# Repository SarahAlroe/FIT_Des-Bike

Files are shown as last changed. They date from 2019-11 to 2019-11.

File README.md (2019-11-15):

# FIT_Des-Bike

Et repo for Grundlæggende IT-produkt Design cykelprojektet.  
Formålet med projektet var at designe og installere et elektronisk system på en cykel.
Der blev i dette tilfælde valgt at bygge et indikator- og positionslys som kunne indikere sving og opbremsning.  
En demonstrationsvideo for projektet kan findes [her](https://youtu.be/tOHQS_oNwDI).

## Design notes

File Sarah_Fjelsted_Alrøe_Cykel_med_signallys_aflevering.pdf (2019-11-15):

Sarah Fjelsted Alrøe | Grundlæggende IT-Produktdesign | 2019-10-04
201905161 | | Dokumentation af cykel

# Cykel med signallys

Videodemonstration af cyklen er vedhæftet, og ellers tilgængelig ved: https://youtu.be/tOHQS_oNwDI

I denne aflevering dokumenteres arbejdet med cykelprojektet, der resulterede i en Arduino-baseret installation, som tilføjer positions-og indikatorlys der kan signallere sving og opbremsninger gennem henholdsvist knapper og et accelerometer. Først beskrives ideen til cyklen, herefter den tekniske udførsel af ideen, og endeligt resultatet, med overvejelser på begrænsninger og besværligheder.

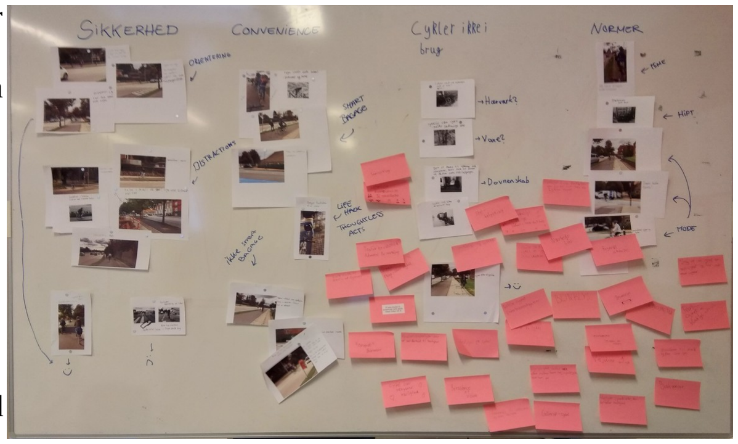
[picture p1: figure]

Der blev taget billeder af cykler og cyklister
i hverdagen. Disse blev grupperet for at
finde tendenser der kunne behandles. Ud fra
disse tendenser blev en række spørgsmål stillet, hvorpå en brainstorm blev udført. Begge ses på figur 1. Dette resulterede i en række ideer, hvorfra en blev udvalgt.

En af de tendenser som blev fundet var cyklisters manglende evne til at kommunikere deres intentioner med cyklen. Traditionelt rækker cylister deres hænder ud for at signallere drej eller stop. Ikke alle cyklister gør dette, og det kan være farligt at signallere hele vejen gennem
handlingen. Ideen til cyklen
er altså gøre signallering
lettere gennem et signal-

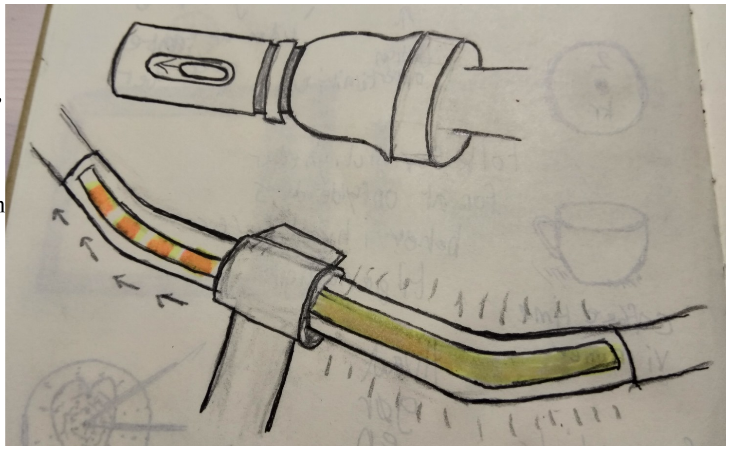
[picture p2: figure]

system i stil med det på biler, som kan indikere sving til højre/venstre, fremad kørsel, samt opbremsning. I styret indlejres slide-kontakter, som skubbes for at starte
indikation af et sving. På baggagebæret og styret
monteres lys som animerer
for at vise cyklistens
intentioner og gøren.
Kontakterne på styret samt lyset er illustreret på figur 2. Figur 2: Skitse af slide-kontakter og lys på styr

Figur 1: Gruppering af observationer og brainstorm

201905161 | Dokumentation af cykel

Der blev skitseret en indpakning til elektronikken som kunne monteres mellem bagagebæret og sædet (Figur 4). Ud fra skitsen blev en 1:1 skummodel konstrueret (Figur 3).

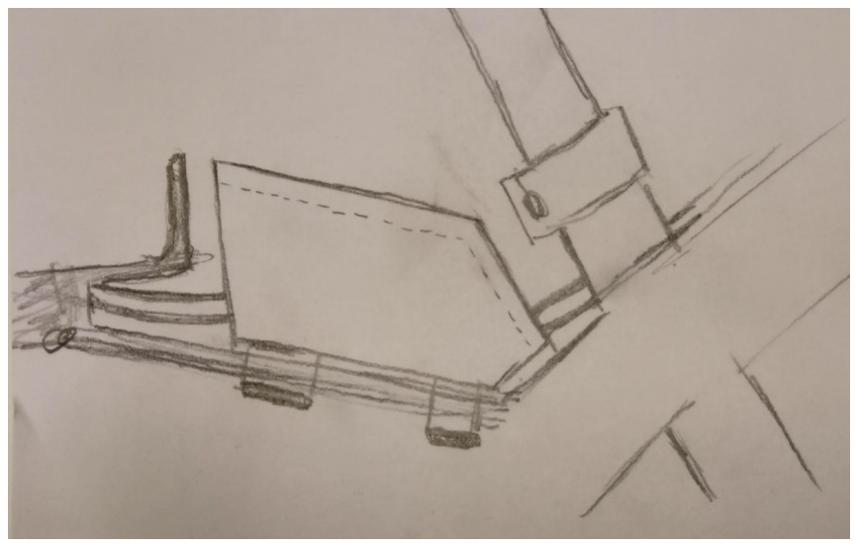
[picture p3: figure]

## Udførsel

Opsætningen består af en Arduino Nano forbundet til en usb power bank. Til Arduinoen er sluttet to
SK6812RGBW strips der sidder foran på cyklen, to

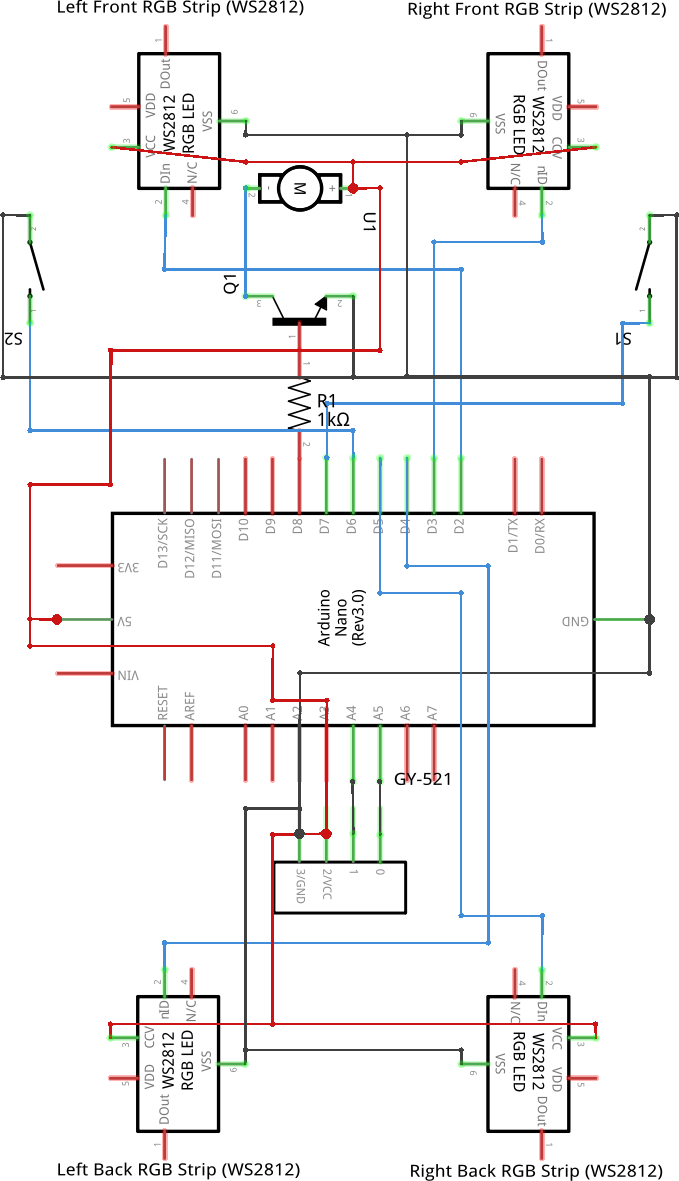
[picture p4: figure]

SK6812RGB strips der sidder bagpå, to pushbuttons som sidder på enden af styrets håndtag, en vibrations-motor på midten af styret drevet med en NPN transistor, samt et GY-521 accelerometer/gyroskop modul. Det fulde kredsløb er optegnet i figur 5.

## Blink

Der kan ved blink indikeres intentioner om at dreje til højre, venstre, eller at køre lige ud. Dette styres med de to knapper på styrets håndtag. For at indikere et drej skubber man sin hånd mod den knap, i hvis retning man ønsker at dreje. Dette fungerer analogt til hvordan man almindeligvis rækker ud for at indikere drej, og forhindrer på samme tid ikke cyklisten i stadig at gøre dette.
I software holdes to tilstande i form af boolean feltvariabler for om der drejes til højre eller venstre. Ved klik på knapperne skiftes disse variabler til deres modsatte værdi. Ud fra disse tilstande vælges mellem fire animationer: Almindeligt kørelys, højresving, venstresving og fremadkørsel som aktiveres ved at klikke i begge retninger. Blink-animationerne fungerer ved at blanke den givne side af LED’erne, og trække et

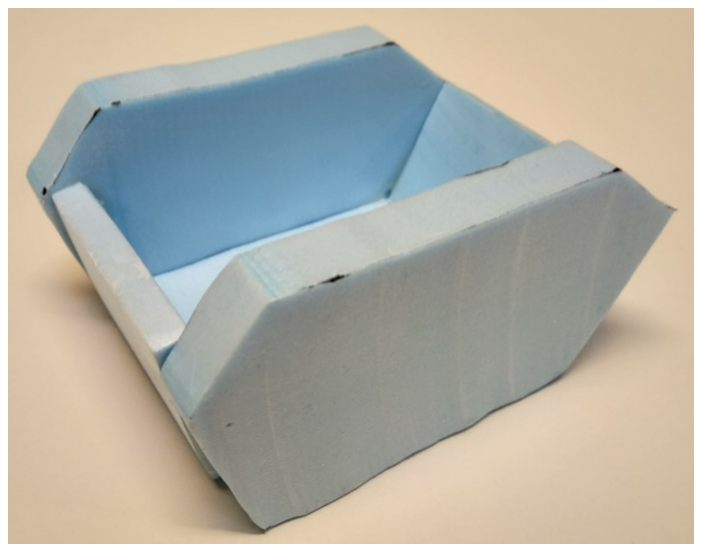
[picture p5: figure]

Figur 5: Kredsløbsdiagram over installationen på cyklen

Figur 4: Skitse af indpakning til elektronik

Figur 3: Skummodel af
indpakning til elektronik

201905161 | Dokumentation af cykel

orange lys i retnignen man drejer. Ved fremad-animationen blinkes begge sider, men lyset bevæger sig indad mod cyklen. Under blink drives foruden en vibrationsmotor for at indikere til cyklisten at de stadig blinker.

## Opbremsning

Opbremsning registreres ved brug af GY-521’ens accelerometer. Omtrendt hver 100ms måles accelerationen i bagudgående retning, og der holdes et løbende gennemsnit på denne værdi. Når den udjævnede værdi krydser over et eksperimentelt bestemt threshold niveau sættes en field variabel, som i animationerne får det røde baglys til at lyse stærkere, eller skifter fra sort til svag rød som baggrund hvis der blinkes.

## Resultat

I demo-videoen kan den endelige opsætning af lys mv. Ses. Mens det var tænkt at montere forlyset på styret, viste dette sig ikke praktisk, så det blev placeret under. Både for-og baglys blev monteret på krydsfinerplader, som blev stripset fast på cyklen. Ligeledes blev der i stedet for slide-knapper brugt simple microswitches på enden af håndtagene man bumper hånden imod.
Opsætningen har været monteret og taget i daglig brug over nogle dage, og nogle besværlighheder har her vist sig. Intet af den brugte elektronik er vandtæt, hvilket var et problem på regnvejrsdage. Elektronikken blev indpakket så godt som muligt i plastikposer vist på figur 6, og der blev taget specielle forhold for at holde cyklen tør. På grund af denne øgede påpasselighed er cyklen langt mere end normalt blevet taget med indendøre. Fordi lysene stikker ud fra cyklen har disse en tendens til at ramme ind i vægge, døre og borde, hvilket flere gange har ledt til at krydsfinerpladerne er knækket. Et tilfælde af dette ses på figur 7.

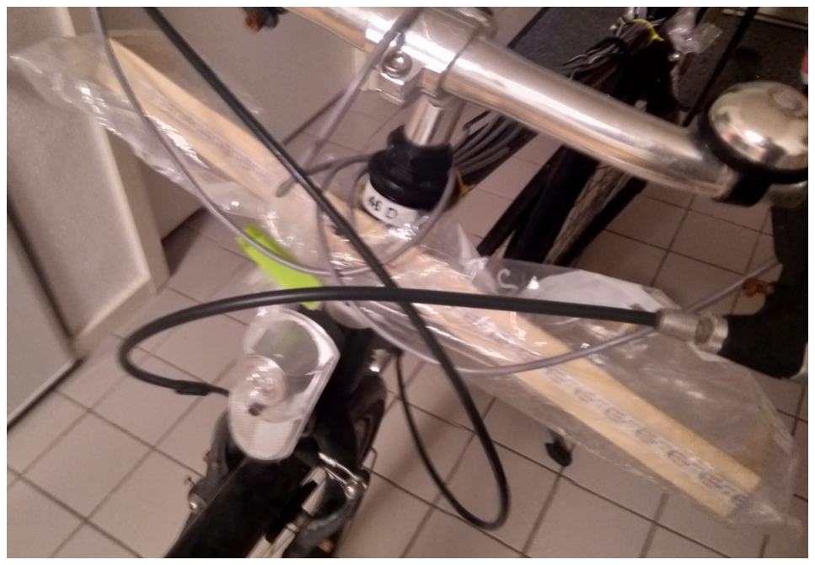
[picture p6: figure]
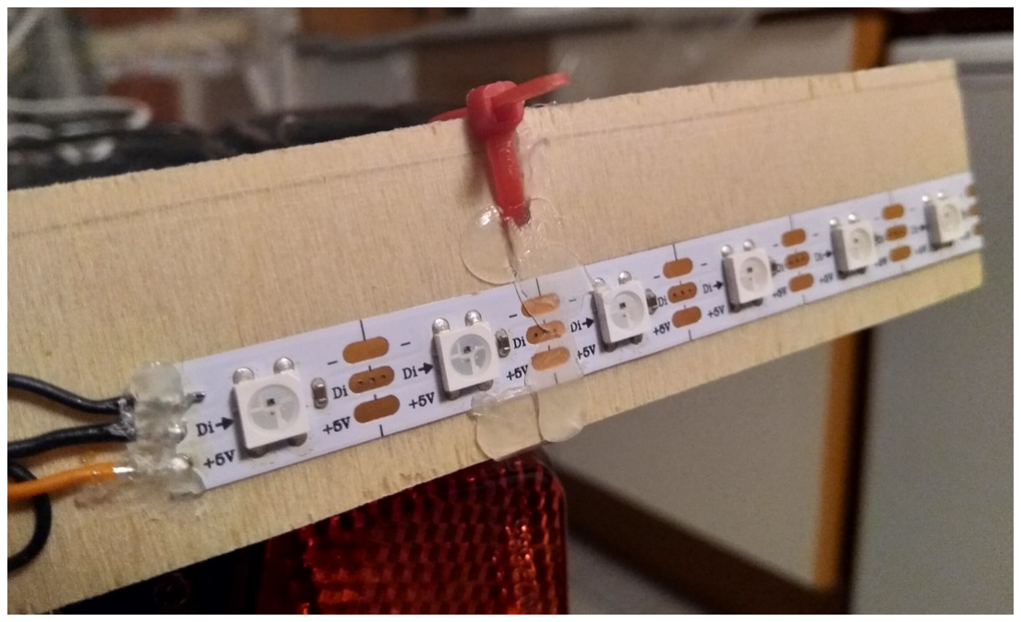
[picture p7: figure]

Figur 6: Lys pakket i plastic poser | Figur 7: Knækket baglys repareret med varmlim

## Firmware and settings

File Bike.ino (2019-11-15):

#include <movingAvg.h>
#include <NeoPixelBus.h>
#include <NeoPixelAnimator.h>
#include <EasyButton.h>
#include<Wire.h>

const int MPU = 0x68;

const int lfPin = 2;
const int rfPin = 3;
const int lbPin = 4;
const int rbPin = 5;

const int lButtonPin = 6;
const int rButtonPin = 7;
const int vibPin = 8;

const int frontNumPixels = 16;
const int backNumPixels = 12;
const uint16_t AnimCount = 1;

const RgbwColor frontIdleColor = RgbwColor(0, 0, 0, 50);
const RgbColor backIdleColor = RgbColor(50, 0, 0);
const RgbColor backIdleColorBreaking = RgbColor(255, 0, 0);
const RgbColor turnColor = RgbColor(255, 50, 0);
const RgbColor invTurnColor = RgbColor(0);
const int turnDarkenAmount = 1;
const int animationSpeed = 600;

const float vibPart = 0.25;

bool breaking = false;
bool turningLeft = false;
bool turningRight = false;

NeoGamma<NeoGammaTableMethod> colorGamma;
NeoPixelBus<NeoGrbwFeature, Neo800KbpsMethod> lfstrip(frontNumPixels, lfPin);
NeoPixelBus<NeoGrbwFeature, Neo800KbpsMethod> rfstrip(frontNumPixels, rfPin);
NeoPixelBus<NeoGrbFeature, Neo800KbpsMethod> lbstrip(backNumPixels, lbPin);
NeoPixelBus<NeoGrbFeature, Neo800KbpsMethod> rbstrip(backNumPixels, rbPin);
NeoPixelAnimator animations(AnimCount);

EasyButton lButton(lButtonPin);
EasyButton rButton(rButtonPin);

const int accFwOff = -874; //Experimentally reached value (Note: very device orientationd dependent)
const int breakingThreshold = 900; //Same
const int accMovingAvgCount = 10;
const int accReadDelay = 100;
unsigned long accLastRead = 0;
movingAvg avgAccFw(accMovingAvgCount);

void lButtonPressedCallBack() {
  if (turningLeft && turningRight) {
    turningLeft = false;
    turningRight = false;
  } else {
    turningLeft = ! turningLeft;
  }
}

void rButtonPressedCallBack() {
  if (turningLeft && turningRight) {
    turningLeft = false;
    turningRight = false;
  } else {
    turningRight = ! turningRight;
  }
}

void handleAnimState() {
  if (turningLeft && turningRight) {
    animations.StartAnimation(0, animationSpeed, ForwardAnimUpdate);
    return;
  }
  if (turningLeft) {
    animations.StartAnimation(0, animationSpeed, LeftAnimUpdate);
    return;
  }
  if (turningRight) {
    animations.StartAnimation(0, animationSpeed, RightAnimUpdate);
    return;
  }
  animations.StartAnimation(0, animationSpeed, IdleAnimUpdate);
}

int towardsClamped(int start, int target, int steps) {
  if (start == target) {
    return start;
  }
  int diff = target - start;
  int sign = (diff > 0) - (diff < 0);
  int dist = sign * steps;
  if (abs(dist) > abs(diff)) {
    dist = diff;
  }
  return start + dist;
}

RgbColor colorTowards(RgbColor start, RgbColor target, int maxAmount) {
  if (start.R == target.R && start.G == target.G && start.B == target.B) {
    return start;
  }

  int r = towardsClamped(start.R, target.R, maxAmount);
  int g = towardsClamped(start.G, target.G, maxAmount);
  int b = towardsClamped(start.B, target.B, maxAmount);

  return RgbColor(r, g, b);
}
RgbwColor colorTowards(RgbwColor start, RgbwColor target, int maxAmount) {
  if (start.R == target.R && start.G == target.G && start.B == target.B && start.W == target.W) {
    return start;
  }

  int r = towardsClamped(start.R, target.R, maxAmount);
  int g = towardsClamped(start.G, target.G, maxAmount);
  int b = towardsClamped(start.B, target.B, maxAmount);
  int w = towardsClamped(start.W, target.W, maxAmount);

  return RgbwColor(r, g, b, w);
}

void fadeStripTowards(NeoPixelBus<NeoGrbFeature, Neo800KbpsMethod> &strip, RgbColor color, int amount) {
  for (uint16_t indexPixel = 0; indexPixel < strip.PixelCount(); indexPixel++)
  {
    strip.SetPixelColor(indexPixel,
                        colorTowards(strip.GetPixelColor(indexPixel), color, amount));
  }
}
void fadeStripTowards(NeoPixelBus<NeoGrbwFeature, Neo800KbpsMethod> &strip, RgbwColor color, int amount) {
  for (uint16_t indexPixel = 0; indexPixel < strip.PixelCount(); indexPixel++)
  {
    strip.SetPixelColor(indexPixel,
                        colorTowards(strip.GetPixelColor(indexPixel), color, amount));
  }
}
void fadeIntervalTowards(NeoPixelBus<NeoGrbFeature, Neo800KbpsMethod> &strip, int i0, int i1, RgbColor color, int amount) {
  for (int i = i0; i <= i1; i++) {
    strip.SetPixelColor(i, colorTowards(strip.GetPixelColor(i), color, amount));
  }
}
void fadeIntervalTowards(NeoPixelBus<NeoGrbwFeature, Neo800KbpsMethod> &strip, int i0, int i1, RgbwColor color, int amount) {
  for (int i = i0; i <= i1; i++) {
    strip.SetPixelColor(i, colorTowards(strip.GetPixelColor(i), color, amount));
  }
}

void handleVib(float progress){
  if (progress<vibPart){
    digitalWrite(vibPin, HIGH);
  }else{
    digitalWrite(vibPin, LOW);
  }
}

void IdleAnimUpdate(const AnimationParam& param) {
  fadeStripTowards(lfstrip, frontIdleColor, turnDarkenAmount);
  fadeStripTowards(rfstrip, frontIdleColor, turnDarkenAmount);
  RgbColor backColor = breaking ? backIdleColorBreaking : backIdleColor;
  fadeStripTowards(lbstrip, backColor, turnDarkenAmount);
  fadeStripTowards(rbstrip, backColor, turnDarkenAmount);

  if (param.state == AnimationState_Completed)
  {
    handleAnimState();
  }
}

void ForwardAnimUpdate(const AnimationParam& param) {
  RgbColor backTurnColor = breaking ? backIdleColor : invTurnColor;
  float progress = param.progress;
  int index;

  handleVib(progress);

  fadeStripTowards(lfstrip, invTurnColor, turnDarkenAmount);
  index = (1.0f - progress) * lfstrip.PixelCount();
  fadeIntervalTowards(lfstrip, index - 1, index + 1, turnColor, turnDarkenAmount * 2);

  fadeStripTowards(lbstrip, backTurnColor, turnDarkenAmount);
  index = (1.0f - progress) * lbstrip.PixelCount();
  fadeIntervalTowards(lbstrip, index - 1, index + 1, turnColor, turnDarkenAmount * 2);

  fadeStripTowards(rfstrip, invTurnColor, turnDarkenAmount);
  index = (1.0f - progress) * rfstrip.PixelCount();
  fadeIntervalTowards(rfstrip, index - 1, index + 1, turnColor, turnDarkenAmount * 2);

  fadeStripTowards(rbstrip, backTurnColor, turnDarkenAmount);
  index = (1.0f - progress) * rbstrip.PixelCount();
  fadeIntervalTowards(rbstrip, index - 1, index + 1, turnColor, turnDarkenAmount * 2);


  if (param.state == AnimationState_Completed)
  {
    handleAnimState();
  }
}

void LeftAnimUpdate(const AnimationParam& param) {
  RgbColor backColor = breaking ? backIdleColorBreaking : backIdleColor;
  RgbColor backTurnColor = breaking ? backIdleColor : invTurnColor;

  float progress = param.progress;
  int index;

  handleVib(progress);

  fadeStripTowards(lfstrip, invTurnColor, turnDarkenAmount);
  index = progress * lfstrip.PixelCount();
  fadeIntervalTowards(lfstrip, index - 1, index + 1, turnColor, turnDarkenAmount * 2);

  fadeStripTowards(lbstrip, backTurnColor, turnDarkenAmount);
  index = progress * lbstrip.PixelCount();
  fadeIntervalTowards(lbstrip, index - 1, index + 1, turnColor, turnDarkenAmount * 2);

  fadeStripTowards(rfstrip, frontIdleColor, turnDarkenAmount);
  fadeStripTowards(rbstrip, backColor, turnDarkenAmount);

  if (param.state == AnimationState_Completed)
  {
    handleAnimState();
  }
}

void RightAnimUpdate(const AnimationParam& param) {
  RgbColor backColor = breaking ? backIdleColorBreaking : backIdleColor;
  RgbColor backTurnColor = breaking ? backIdleColor : invTurnColor;

  float progress = param.progress;
  int index;

  handleVib(progress);

  fadeStripTowards(rfstrip, invTurnColor, turnDarkenAmount);
  index = progress * rfstrip.PixelCount();
  fadeIntervalTowards(rfstrip, index - 1, index + 1, turnColor, turnDarkenAmount * 2);

  fadeStripTowards(rbstrip, backTurnColor, turnDarkenAmount);
  index = progress * rbstrip.PixelCount();
  fadeIntervalTowards(rbstrip, index - 1, index + 1, turnColor, turnDarkenAmount * 2);

  fadeStripTowards(lfstrip, frontIdleColor, turnDarkenAmount);
  fadeStripTowards(lbstrip, backColor, turnDarkenAmount);

  if (param.state == AnimationState_Completed)
  {
    handleAnimState();
  }
}

void setupAccelerometer() {
  Wire.begin();
  Wire.beginTransmission(MPU);
  Wire.write(0x6B);
  Wire.write(0);
  Wire.endTransmission(true);
}

int16_t readAcceleration() {
  if (accLastRead + accReadDelay < millis()) {
    accLastRead = millis();
    Wire.beginTransmission(MPU);
    Wire.write(0x3B);
    Wire.endTransmission(false);
    Wire.requestFrom(MPU, 2, true);
    return avgAccFw.reading((Wire.read() << 8 | Wire.read()) + accFwOff);
  }else{
    return avgAccFw.getAvg();
  }

}

void setup() {
  pinMode(vibPin, OUTPUT);
  setupAccelerometer();

  lButton.begin();
  rButton.begin();
  lButton.onPressed(lButtonPressedCallBack);
  rButton.onPressed(rButtonPressedCallBack);

  avgAccFw.begin();

  lfstrip.Begin();
  rfstrip.Begin();
  lbstrip.Begin();
  rbstrip.Begin();

  lfstrip.Show();
  rfstrip.Show();
  lbstrip.Show();
  rbstrip.Show();

  animations.StartAnimation(0, animationSpeed, IdleAnimUpdate);
}

void loop() {
  lButton.read();
  rButton.read();

  breaking = readAcceleration() > breakingThreshold;

  animations.UpdateAnimations();
  lfstrip.Show();
  rfstrip.Show();
  lbstrip.Show();
  rbstrip.Show();
}

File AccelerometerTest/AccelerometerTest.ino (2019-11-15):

#include <movingAvg.h>

#include<Wire.h>
#include <math.h>

const int MPU=0x68;
int16_t AcX,AcY,AcZ,Tmp,GyX,GyY,GyZ;
double pitch,roll;
float averageX = 0;
int counter =0;

movingAvg avgX(5);

void setup(){
Wire.begin();
Wire.beginTransmission(MPU);
Wire.write(0x6B);
Wire.write(0);
Wire.endTransmission(true);
Serial.begin(9600);
avgX.begin();
}
void loop(){
Wire.beginTransmission(MPU);
Wire.write(0x3B);
Wire.endTransmission(false);
Wire.requestFrom(MPU,2,true);

int AcXoff,AcYoff,AcZoff,GyXoff,GyYoff,GyZoff;
int temp,toff;
double t,tx,tf;

//Acceleration data correction
AcXoff = -874;
AcYoff = +96;
AcZoff = -475;

//Temperature correction
toff = -1600;

//Gyro correction
GyXoff = 480;
GyYoff = 170;
GyZoff = 210;

//read accel data
AcX=(Wire.read()<<8|Wire.read()) + AcXoff;
/*AcY=(Wire.read()<<8|Wire.read()) + AcYoff;
AcZ=(Wire.read()<<8|Wire.read()) + AcYoff;

//read temperature data
temp=(Wire.read()<<8|Wire.read()) + toff;
tx=temp;
t = tx/340 + 36.53;
tf = (t * 9/5) + 32;

//read gyro data
GyX=(Wire.read()<<8|Wire.read()) + GyXoff;
GyY=(Wire.read()<<8|Wire.read()) + GyYoff;
GyZ=(Wire.read()<<8|Wire.read()) + GyZoff;*/

//get pitch/roll
//getAngle(AcX,AcY,AcZ);

//send the data out the serial port
/*Serial.print("Angle: ");
Serial.print("Pitch = "); Serial.print(pitch);
Serial.print(" | Roll = "); Serial.println(roll);

Serial.print("Temp: ");
Serial.print("Temp(F) = "); Serial.print(tf);
Serial.print(" | Temp(C) = "); Serial.println(t);

Serial.print("Accelerometer: ");
Serial.print("X = "); Serial.print(AcX);
Serial.print(" | Y = "); Serial.print(AcY);
Serial.print(" | Z = "); Serial.println(AcZ);

Serial.print("Gyroscope: ");
Serial.print("X = "); Serial.print(GyX);
Serial.print(" | Y = "); Serial.print(GyY);
Serial.print(" | Z = "); Serial.println(GyZ);
Serial.println(" ");*/
/*Serial.print(AcX);
Serial.print(", ");
Serial.print(AcY);
Serial.print(", ");*/
Serial.println(avgX.reading(AcX)>900);
delay(100);
/*averageX += AcX;
if (counter<10){
  counter ++;
}else{
  counter = 0;
  averageX /=10;
  Serial.println(AcX);
}*/
}

//convert the accel data to pitch/roll
void getAngle(int Vx,int Vy,int Vz) {
double x = Vx;
double y = Vy;
double z = Vz;

pitch = atan(x/sqrt((y*y) + (z*z)));
roll = atan(y/sqrt((x*x) + (z*z)));
//convert radians into degrees
pitch = pitch * (180.0/3.14);
roll = roll * (180.0/3.14) ;

}
